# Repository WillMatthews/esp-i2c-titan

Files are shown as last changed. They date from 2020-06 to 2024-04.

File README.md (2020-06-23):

# esp-i2c-titan
nodemcu breakout board to drive overview titan

## Kicad/
Contains the PCB layout to drive an Overview titan through flatflex connector J2.

## arduino/
Contains the arduino code required to program an ESP8266 nodeMCU dev board to interface with the polariser.

## matlab/
Contains MATLAB code to interface with the ESP8266 over a serial interface.

## todo:
- CAD mount for the polariser.

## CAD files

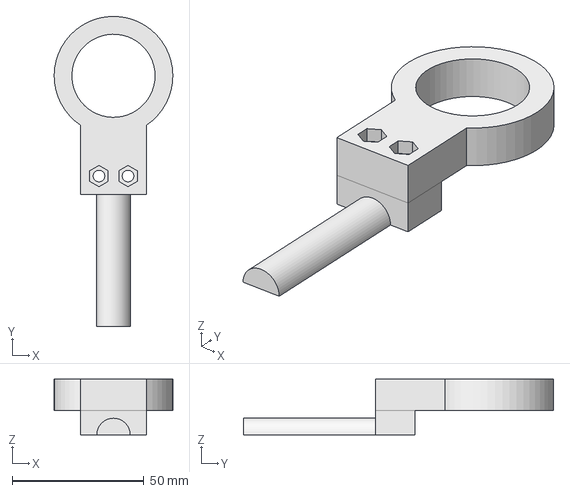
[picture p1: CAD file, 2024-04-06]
polariser_mount.FCStd
45.0 x 117.5 x 21.2 mm

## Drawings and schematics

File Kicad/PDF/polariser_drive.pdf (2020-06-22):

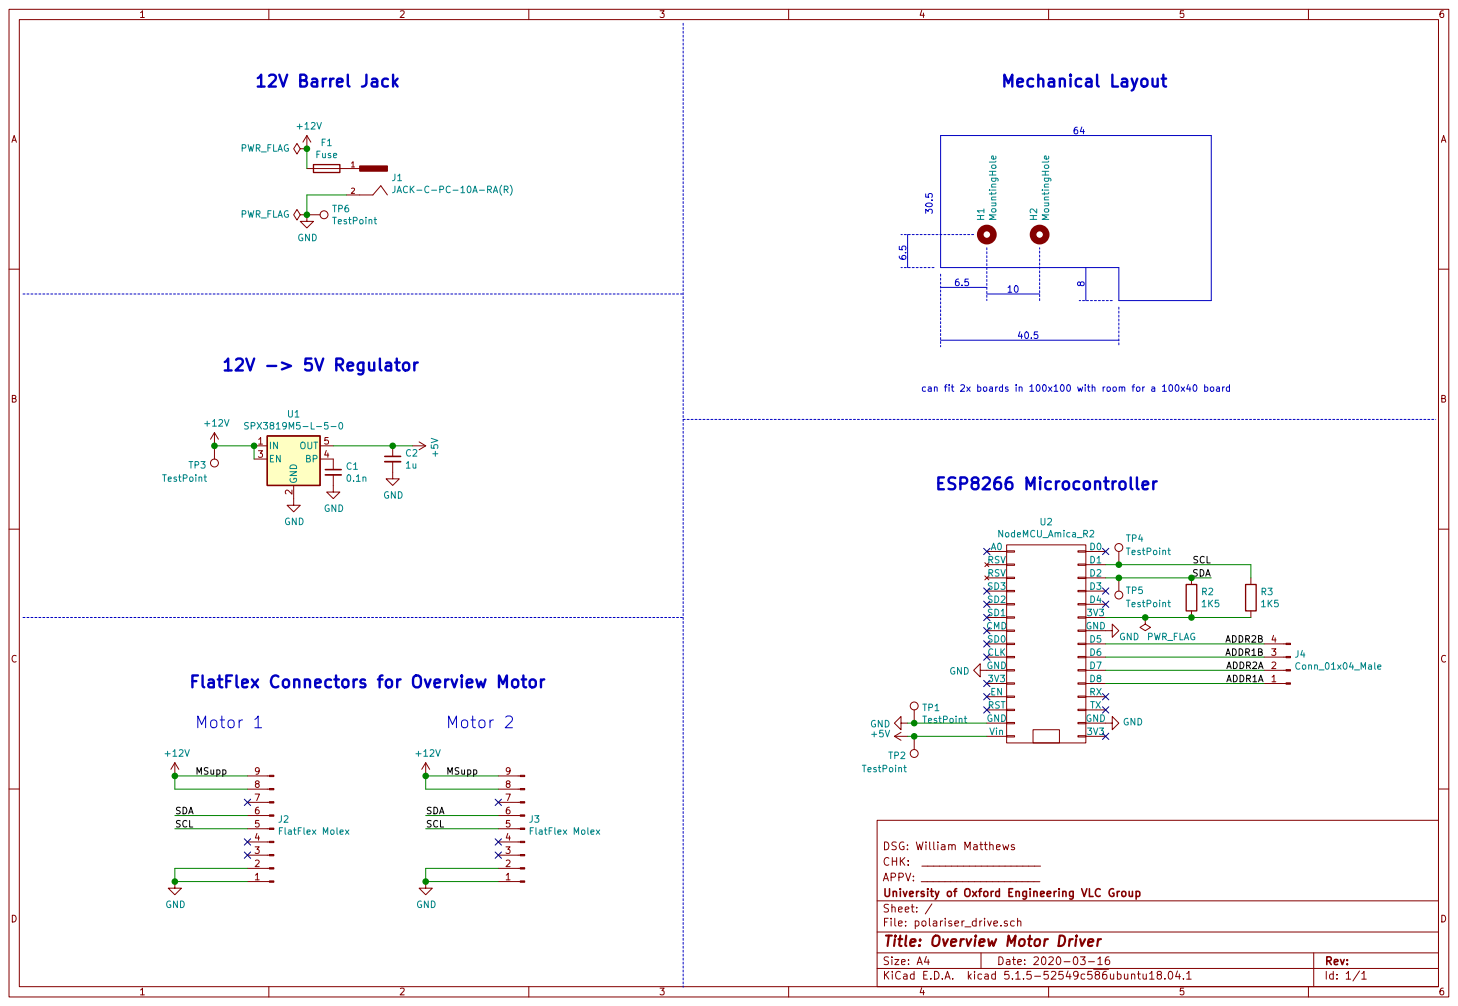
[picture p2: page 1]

can fit 2x boards in 100x100 with room for a 100x40 board Mechanical Layout

2 EN 3 BP 4 OUT 5 U1 SPX3819M5-L-5-0 +5V GND

FlatFlex Connectors for Overview Motor

CHK: ____________________ DSG: William Matthews

APPV: ____________________
File: polariser_drive.sch Sheet: / University of Oxford Engineering VLC Group

Id: 1/1 Title: Overview Motor Driver

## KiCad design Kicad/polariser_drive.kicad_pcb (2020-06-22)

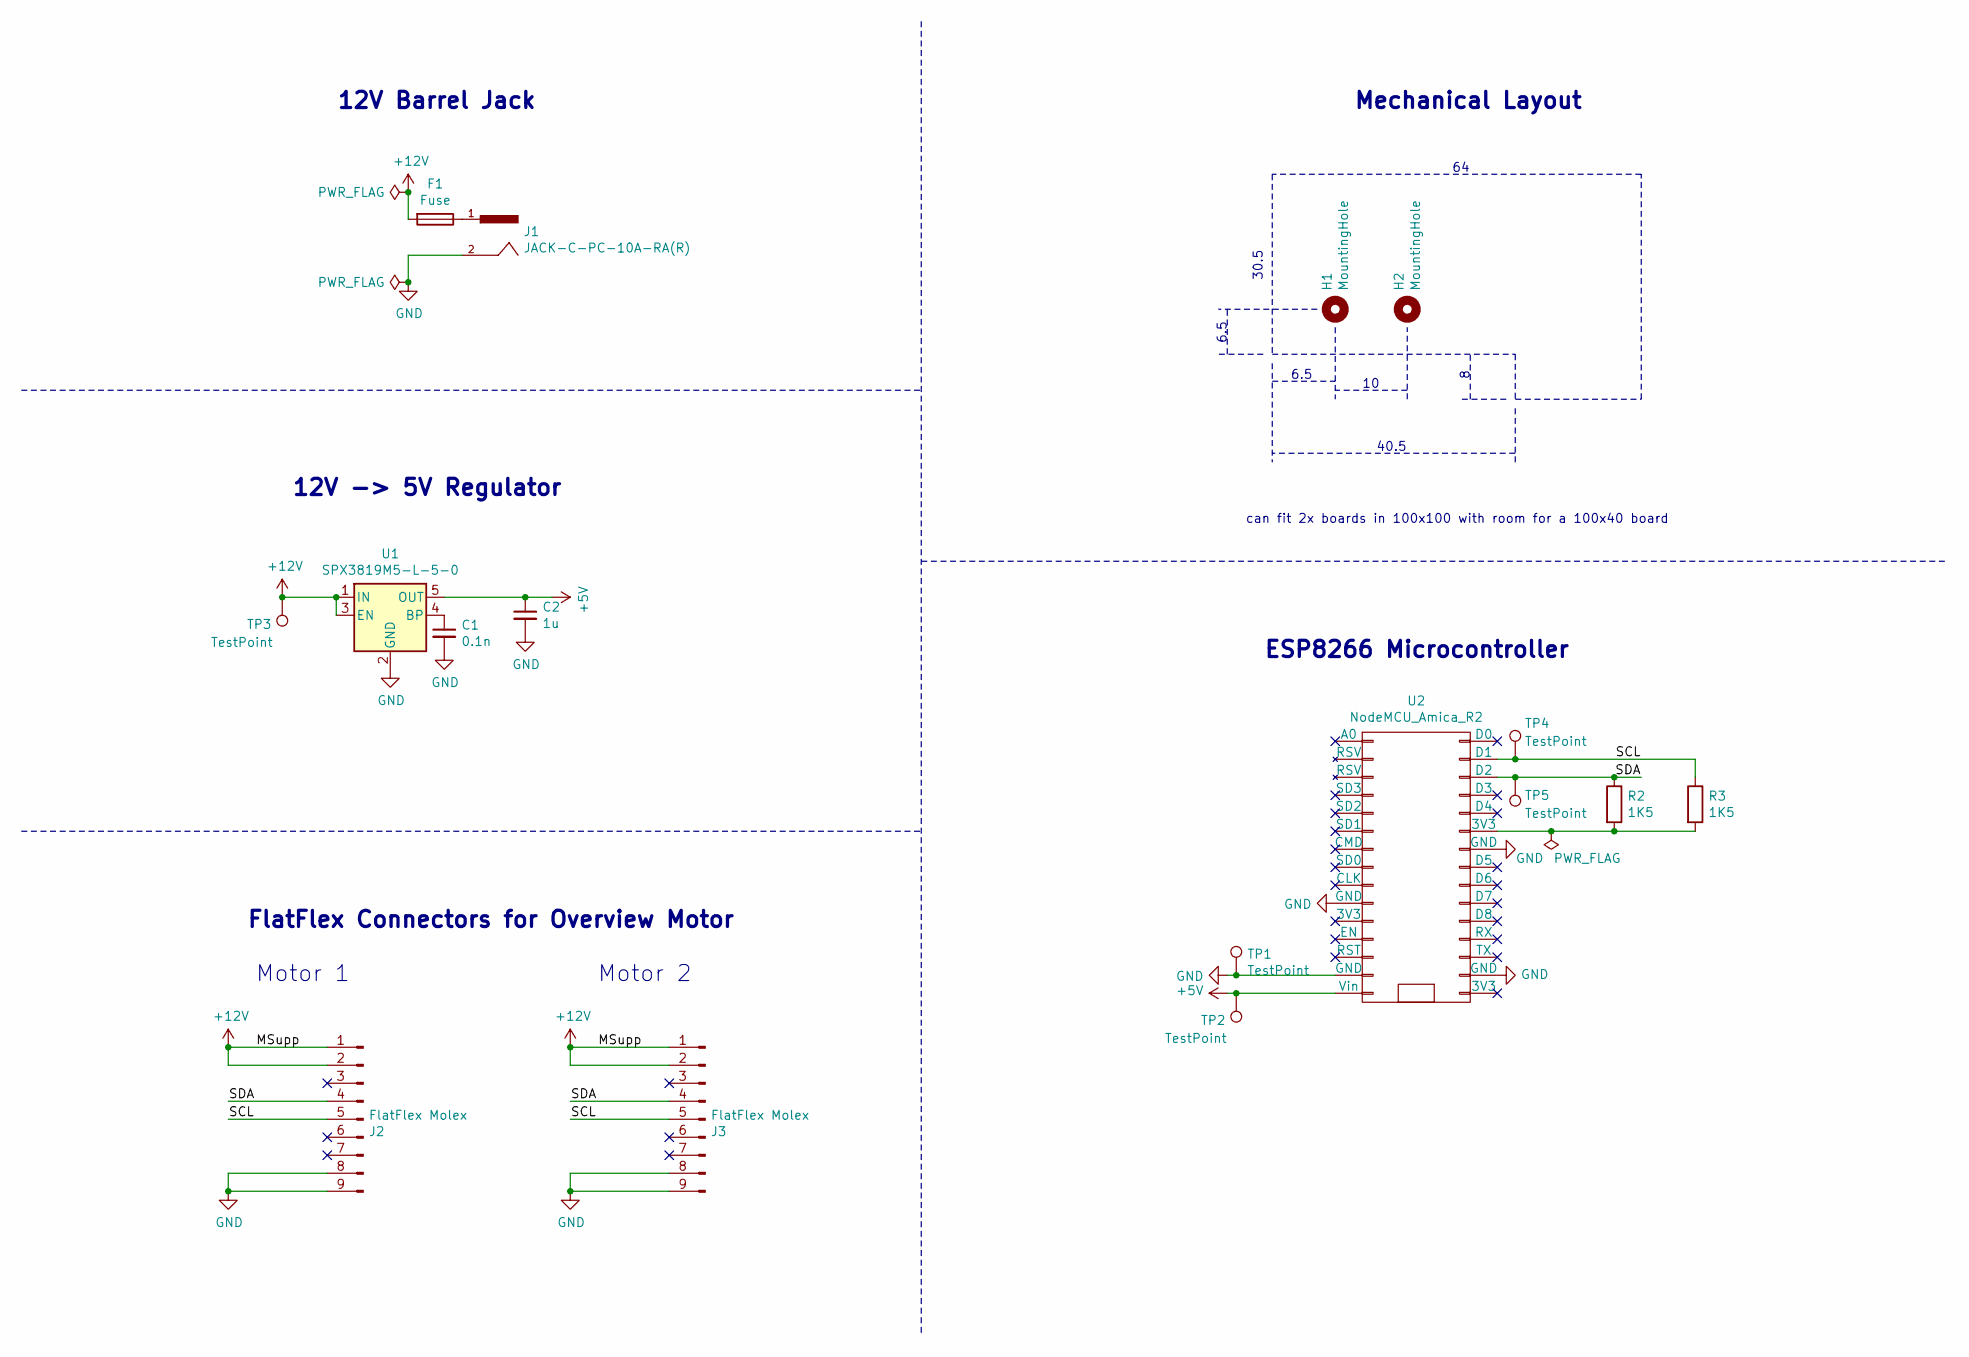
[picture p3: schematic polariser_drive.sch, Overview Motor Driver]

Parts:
C1: 0.1n; Fuse_1206_3216Metric_Pad1.42x1.75mm_HandSolder
C2: 1u; C_0805_2012Metric_Pad1.15x1.40mm_HandSolder
F1: Fuse; R_Axial_DIN0309_L9.0mm_D3.2mm_P12.70mm_Horizontal
H1, H2: MountingHole; MountingHole_4.3mm_M4
J1: JACK-C-PC-10A-RA(R); GLOBTECK_JACK-C-PC-10A-RA(R); Part 1939-1434-ND
J2, J3: FlatFlex Molex; 9pos; PartA WM7958CT-ND
R2, R3: 1K5; R_0805_2012Metric
TP1, TP2, TP3: TestPoint; TestPoint_Pad_D1.5mm
TP4, TP5: TestPoint; PinHeader_1x01_P2.54mm_Vertical
U1: SPX3819M5-L-5-0; SOT-23-5; Part 1016-1874-1-ND
U2: NodeMCU_Amica_R2

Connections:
+5V: C2.1, TP2.1, U1.5 (OUT), U2.15 (Vin)
+12V: F1.2, J2.1, J2.2, J3.1, J3.2, TP3.1, U1.1 (IN), U1.3 (EN)
/SCL: J2.5, J3.5, R3.1, TP4.1, U2.29 (D1)
/SDA: J2.4, J3.4, R2.1, TP5.1, U2.28 (D2)
GND: C1.2, C2.2, J1.2, J2.8, J2.9, J3.8, J3.9, TP1.1, U1.2 (GND), U2.10 (GND), U2.14 (GND), U2.17 (GND), U2.24 (GND)
unnamed: C1.1, U1.4 (BP)
unnamed: F1.1, J1.1
unnamed: R2.2, R3.2, U2.25 (3V3)

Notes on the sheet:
ESP8266 Microcontroller
can fit 2x boards in 100x100 with room for a 100x40 board
Mechanical Layout
12V -> 5V Regulator
12V Barrel Jack
FlatFlex Connectors for Overview Motor
Motor 2
Motor 1
6.5
40.5
30.5

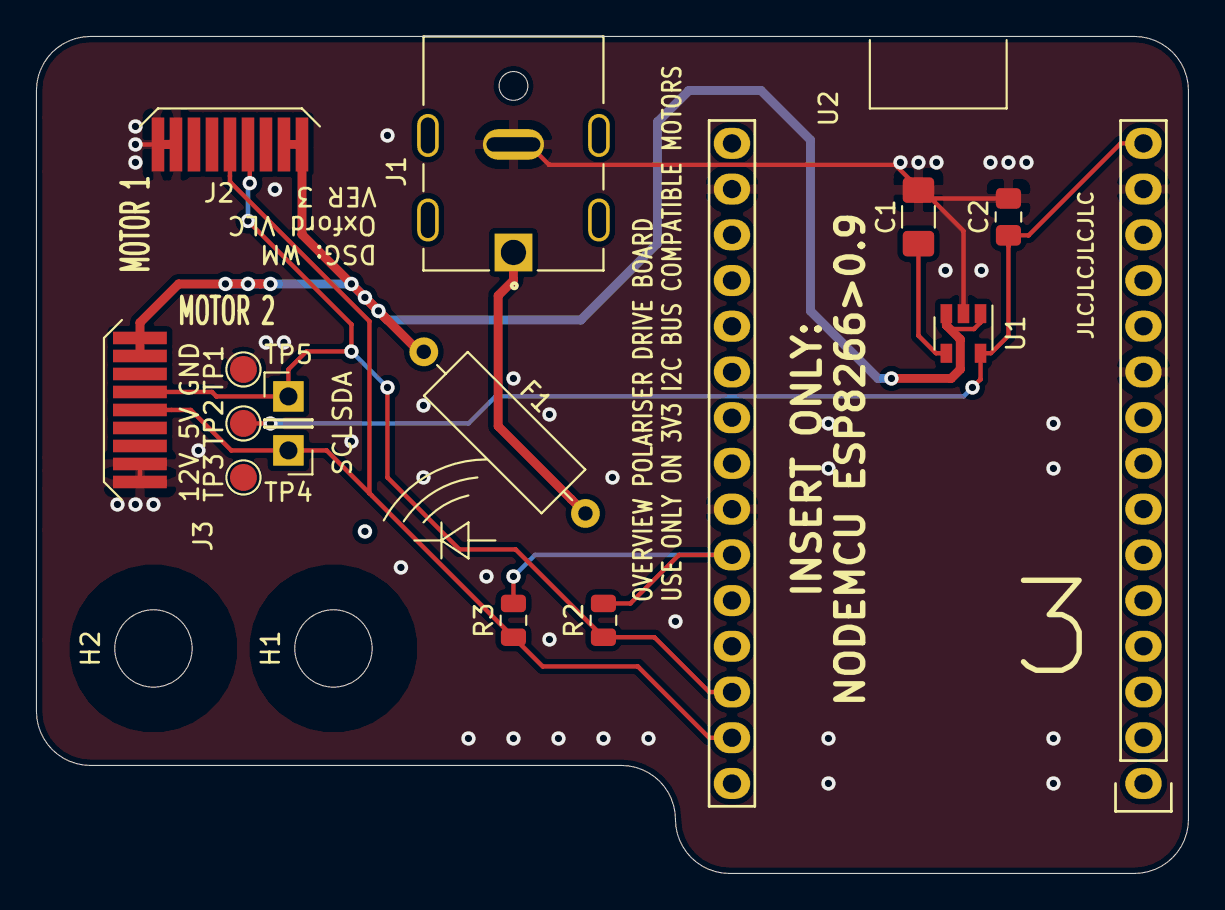
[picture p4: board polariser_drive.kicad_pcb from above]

Board: 2 copper layers, 64.0 x 46.5 mm, 17 parts (0 on the bottom side), 8 nets.

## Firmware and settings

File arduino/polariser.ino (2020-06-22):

#include <Arduino.h>
#include <ESP8266WiFi.h>
#include <Wire.h>

const byte PIN_DEBUG = 16;
const byte PIN_CLOCK = 4;
const byte PIN_DATA = 5;

const byte dev = 0x28; // this is actually a 7 bit I2C address but a byte works fine (despite compile warns)

void setup() {
  WiFi.mode(WIFI_OFF);
  WiFi.forceSleepBegin();
  pinMode(PIN_DEBUG, OUTPUT);
  Wire.begin();
  Serial.begin(9600);
}

void loop() {
  unsigned int totalsteps = 0xFFFF; //65535 steps per revolution -> 0.005493248 deg per step.
                                    // 1 degree ~ 182 counts.
  digitalWrite(PIN_DEBUG,HIGH);

  
  if (Serial.available()){
    String command = Serial.readStringUntil('\n');


    // QRY ANGLE
    if (command.equals(":MEAS:ANGLE")) {
      //0x04 current location
      Wire.beginTransmission(dev); // transmit to device #28 (jumper on pin 2-3)
      Wire.write(0x04);            // sends two bytes
      Wire.endTransmission();      // stop transmitting
      
      Wire.requestFrom(dev,2);
      int i = 0;
      unsigned int high_byte = 0;
      unsigned int low_byte = 0;
      
      while(Wire.available())    // motor may send fewer or more than requested
      { 
        unsigned int c = Wire.read();    // receive a byte as a uint
        if (i == 0){
          high_byte = c;  // first byte is MSB
        } else {
          low_byte = c;   // second byte is LSB
        }
          i++;
      }
      
      unsigned int angle_at = ((unsigned int)high_byte << 8) + low_byte; // combine LSB and MSB
      float angle_atdeg = 360.0 * float(angle_at) / float(totalsteps);   // convert from steps to degrees

      // round to 4dp    
      char str_out[7];
      dtostrf(angle_atdeg,3,4,str_out);

      // output as qry response
      Serial.write(str_out);
      Serial.write("\n");






    // QRY IS MOTOR MOVING
    } else if (command.equals(":MEAS:MOVE")) {

     //0x03 Is Motor Moving?
      Wire.beginTransmission(dev); // transmit to device #28 (pin 2-3)
      Wire.write(0x03);            // sends a byte (request for IS MOTOR MOVING)
      Wire.endTransmission();      // stop transmitting
      
      Wire.requestFrom(dev,1);     // request one byte
      
      int i = 0;
      unsigned int state_byte = 0;
      while(Wire.available())    // motor may send fewer or more than requested
      { 
        unsigned int c = Wire.read();    // receive the first byte as a uint
        if (i == 0){
          state_byte = c;
        }
          i++;
      }

      // output qry response
      if (state_byte == 0xFF || state_byte == 0x01){
        Serial.write("1"); // motor is moving
      } else if (state_byte == 0x00) {
        Serial.write("0"); // motor is stationary
      } else {
        Serial.write("E"); // error
      }
      Serial.write("\n");



    // if not a query we are seeing an angle goto request.
    } else {
      float degrees = command.toFloat();
    
      unsigned int out = round(totalsteps * degrees/360); // convert degrees request to motor steps
      // range 0x0000-0xFFFF
      byte data0 = highByte(out);  // data0 MSB
      byte data1 = lowByte(out);   // data1 LSB
    
      // ADDR 0x28, 0x50 LEFT SHIFT
      Wire.beginTransmission(dev); // transmit to device #28 (pin 2-3 on jumper)
        
      Wire.write(0x05);            // sends one byte (0x05 -> goto absolute location)
      Wire.write(data0);           // sends one byte  
      Wire.write(data1);           // sends one byte
      Wire.endTransmission();      // stop transmitting
      }
  }
}

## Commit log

2020-03-14 board first ver
    [polariser_drive.kicad_pcb, polariser_drive.sch]
2020-03-16 add another connector and configurable address lines
    [polariser_drive-B_Cu.gbr, polariser_drive-B_Mask.gbr, polariser_drive-B_Paste.gbr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]
2020-03-16 add note on sch
    [polariser_drive.sch]
2020-04-24 stupid rookie footprint error
    [polariser_drive-B_Cu.gbr, polariser_drive-B_Mask.gbr, polariser_drive-B_Paste.gbr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]
2020-06-22 board finished
    [polariser_drive-B_Cu.gbr, polariser_drive-B_Mask.gbr, polariser_drive-B_Paste.gbr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]
2020-06-22 added arduino code and matlab drive code
    [polariser_drive-B_Cu.gbr, polariser_drive-B_Mask.gbr, polariser_drive-B_Paste.gbr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]
2024-04-06 add noddy board mount
    [polariser_mount.FCStd]
